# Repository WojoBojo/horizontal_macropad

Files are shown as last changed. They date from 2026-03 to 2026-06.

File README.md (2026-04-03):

# WojRaf's macropad
A wireless 16 key horizontal macropad, made for Hack Club Blueprint 2026

I always liked the idea of macropads, but I didn't like the "box" style (usualy a 4 x 4 grid of buttons). What I wanted was a horizontal (1 x 16 grid of buttons) version, that I could put on top of my keyboard (like a row of function keys).

So I came up with something like this:


The biggest challenge was the PCB - I started learning how to make one in KiCad, but I ended up using EasyEDA because in my opinion it is a bit more user-friendly.



The hardware consists of:

- ESP32 S3 Wroom 1
- 16 Kalih BOX switches
- Alps Alpine rotary encoder
- USB-C port for charging and programing
- 18650 2600mAh 3.7V battery

# How to use
1. Plug in the macropad via cable to your computer.

2. Open the macropad.ino file in Arduino IDE, select ESP32S3 Dev Module as the board and flash the firmware.

2. With the macropad still connected via cable, open the serial monitor, and chose 115200 as the baud rate.

# Commands
list - shows the current key mapping.

bind - changes the key's function (example: bind 5 F1 - changes key nr. 5 to F1 (Function 1 key)).

save - saves the changes to flash (keeps data after restart)

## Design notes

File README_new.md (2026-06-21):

# Horizontal Macropad 🎹



A wireless 16-key horizontal macropad, designed for [Hack Club Blueprint 2026](https://blueprint.hackclub.com).

I always liked macropads but never liked the boxy 4×4 grid. I wanted a horizontal row — like a function key row — that sits on top of your keyboard. So I built one.

---

## ✨ Features

| Feature | Details |
|---|---|
| **16 keys** | Kailh BOX switches via CD74HC4067 mux (saves GPIOs) |
| **Rotary encoder** | EC11E1834403 (ALPS) — volume / scroll by default |
| **Battery** | 18650 2600mAh with BQ24074 charger + TPS63031 buck-boost |
| **USB-C** | Charging only (data lines unpopulated) |
| **Wireless** | ESP32-S3 + on-board PCB antenna |
| **Persistent keymap** | Save key bindings to flash — survive reboot |
| **Configurable** | Remap any key over serial — no reflashing needed |

---

## 📁 Repository Structure

```
hardware/            ← PCB design files
├── PCB.pdf          ← PCB layout printable
├── PCB.png          ← PCB layout preview
├── Schematic.pdf    ← Circuit schematic printable
├── Schematic.png    ← Circuit schematic preview
└── EasyEDA/         ← Editable source files (EasyEDA Pro)
    ├── PCB.epro
    └── Schematic.epro

case/                ← 3D-printed enclosure
├── MacropadCase.step   ← STEP file (CAD)
└── MacropadCase_.f3z   ← Fusion 360 archive

firmware/            ← ESP32-S3 code
├── HackClub_Macropad.ino       ← Original firmware (minimal)
└── HackClub_Macropad_new.ino   ← Full rewrite (encoder, battery, keymap)

manufacturing/       ← Ready-to-order files
└── gerbers.zip      ← PCB Gerber + drill + flying probe

BOM.csv              ← Bill of Materials (LCSC part numbers)

README.md            ← This file (original)
README_new.md        ← This file (updated)
```

---

## 🚀 Quick Start

### 1. Order the PCB
Upload `manufacturing/gerbers.zip` + `BOM.csv` to [JLCPCB](https://jlcpcb.com) or your preferred fab.

| Item | Est. cost (5 pcs) |
|---|---|
| PCB 302×38mm (2-layer) | ~$20 |
| PCBA (top side assembly) | ~$40 |
| Components (LCSC) | ~$45 |
| **Total prototype** | **~$105** |

### 2. Print the case
`case/MacropadCase.step` — print on any FDM or resin printer.

### 3. Flash the firmware

**Recommended:** `firmware/HackClub_Macropad_new.ino`
- Open in **Arduino IDE 2.x**
- Board: `ESP32S3 Dev Module`
- Flash via **UART** (GPIO43=TX, GPIO44=RX) or solder 0Ω resistors on pads e40/e41 for native USB

> ⚠️ **Programming note:** USB-C on this board is charging-only. Data lines are unpopulated. Use a USB-UART adapter (e.g. CP2102) connected to GPIO43/44, or populate 0Ω resistors to enable native USB.

### 4. Configure key bindings

Open Serial Monitor at **115200 baud**:

```
list              → show current key map
bind 5 F1         → set key #5 to F1
bind 0 A          → set key #0 to letter A
save              → persist to flash (survives reboot)
load              → reload from flash
default           → restore factory defaults
battery           → show battery voltage
encoder           → show encoder position
```

### 5. Mount on keyboard
The horizontal form sits perfectly above your function keys. Use double-sided tape or screw holes (add your own — PCB doesn't include M3 holes in this rev).

---

## 🔌 Pin Map

| Signal | GPIO | Function |
|---|---|---|
| MUX_OUT | 1 | CD74HC4067 common (pull-up) |
| S0–S3 | 4–7 | Mux address lines |
| ENC_A | 18 | Rotary encoder phase A |
| ENC_B | 19 | Rotary encoder phase B (no conflict — USB data NC) |
| ENC_SW | — | **Not routed** on this PCB (pads D/E empty) |
| BAT_ADC | 39 | Battery voltage divider (ADC1) |

---

## 🛠 PCB Revision Notes

This is **v1.0** of the design. Things to fix in the next spin:

- [ ] **Add ground pour** — no copper fill on either layer → EMI risk for ESP32 @240MHz
- [ ] **Add M3 mounting holes** — 300mm board needs mechanical support
- [ ] **External pull-up on MUX_OUT** — internal INPUT_PULLUP (~45k) is marginal on long traces
- [ ] **Wire encoder push button** — pads D/E of EC11E1834403 are unconnected
- [ ] **TVS diode on VBUS** — ESD protection for USB-C
- [ ] **Thicker power traces** — VBAT and 3.3V should be ≥0.5mm wide

---

## 🏆 Made For Hack Club Blueprint 2026

Built from scratch — KiCad → EasyEDA → breadboard → PCB → case → firmware.

Thanks to [Hack Club](https://hackclub.com) for the opportunity and funding!

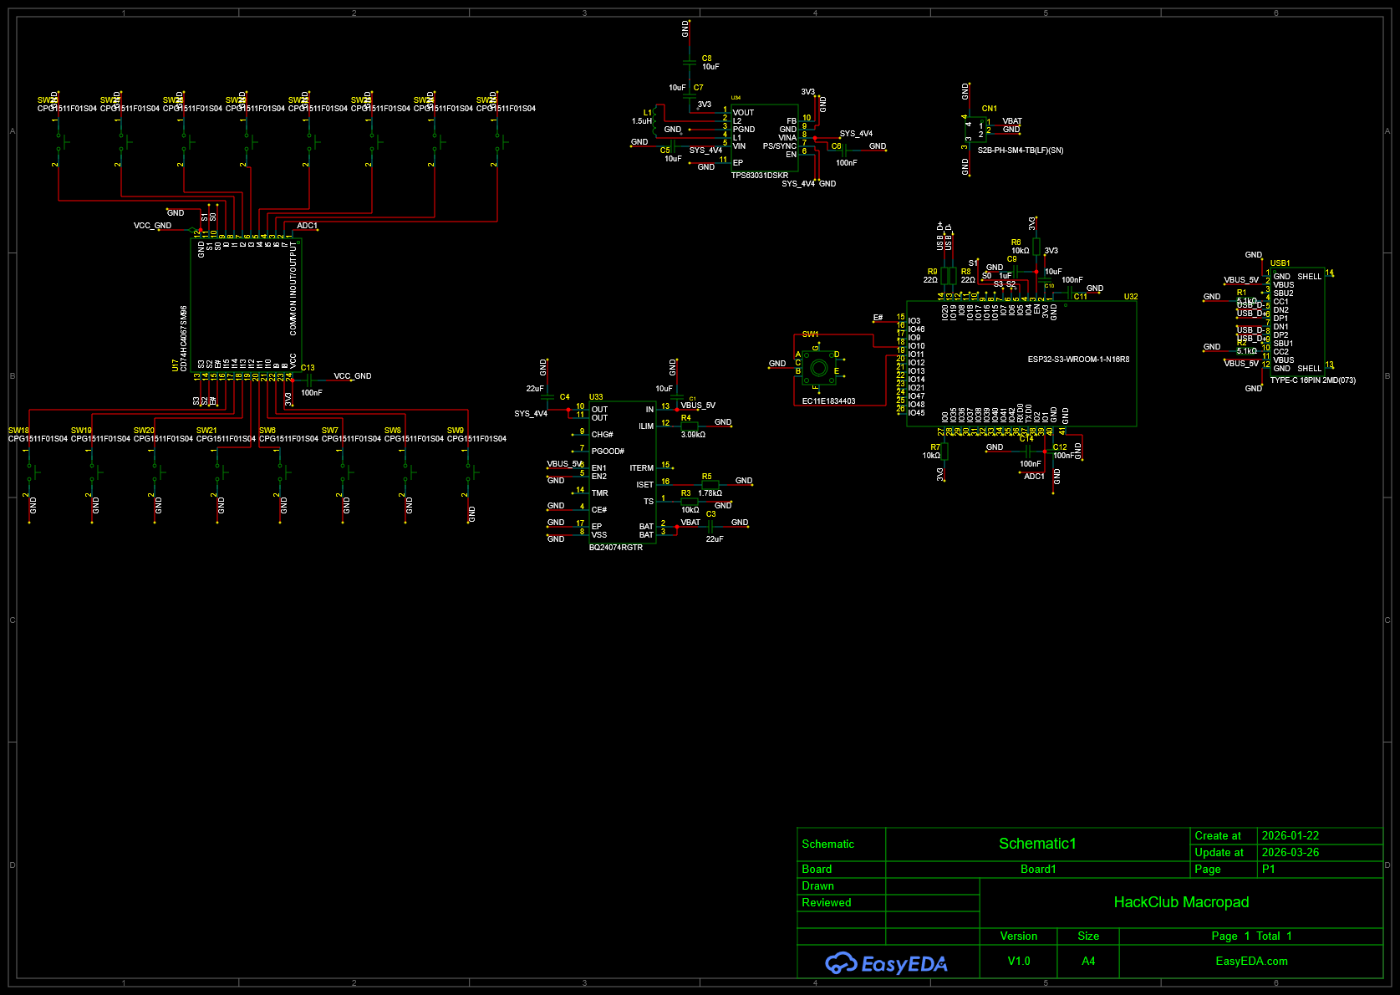
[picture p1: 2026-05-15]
hardware/Schematic.png

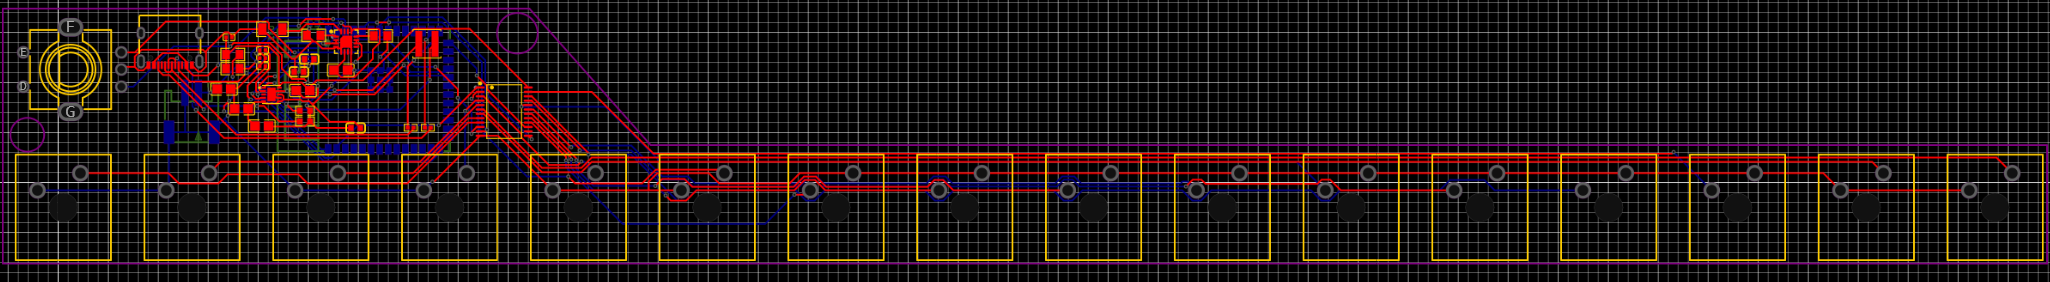
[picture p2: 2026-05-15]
hardware/PCB.png

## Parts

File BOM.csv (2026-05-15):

No. | Quantity | Comment | Designator | Footprint | Value | Manufacturer Part | Manufacturer | Supplier Part | Links
1 | 16 | CPG1511F01S04 | SW6,SW7,SW8,SW9,SW18,SW19,SW20,SW21,SW22,SW23,SW24,SW25,SW26,SW27,SW28,SW29 | KEY-TH_CPG1511F01S0X |  | CPG1511F01S04 | Kailh(凯华) | C400226 | https://www.kailh.net/products/kailh-box-switch-set?variant=43810892284146
2 | 4 | 100nF | C11,C12,C13,C14 | C0402 | 100nF | CL05B104KB54PNC | SAMSUNG(三星) | C307331 | https://www.lcsc.com/product-detail/C307331.html?s_z=n_C307331
3 | 3 | 10uF | C5,C7,C8 | C0603 | 10uF | CL10A106KP8NNNC | SAMSUNG(三星) | C19702 | https://www.lcsc.com/product-detail/C19702.html?s_z=n_C19702
4 | 2 | 5.1kΩ | R1,R2 | R0603 | 5.1kΩ | 0603WAF5101T5E | UNI-ROYAL(厚声) | C23186 | https://www.lcsc.com/product-detail/C23186.html?s_z=n_C23186
5 | 2 | 10uF | C1,C10 | C0805 | 10uF | CC0805KKX5R7BB106 | YAGEO(国巨) | C89827 | https://www.lcsc.com/product-detail/C89827.html?s_z=n_C89827
6 | 2 | 22uF | C3,C4 | C0805 | 22uF | CL21A226MPQNNNE | SAMSUNG(三星) | C29277 | https://www.lcsc.com/product-detail/C29277.html?s_z=n_C29277
7 | 2 | 10kΩ | R6,R7 | R0805 | 10kΩ | RC0805FR-0710KL | YAGEO(国巨) | C84376 | https://www.lcsc.com/product-detail/C84376.html?s_z=n_C84376
8 | 2 | 22Ω | R8,R9 | R0402 | 22Ω | RC0402FR-0722RL | YAGEO(国巨) | C114765 | https://www.lcsc.com/product-detail/C114765.html?s_z=n_C114765
9 | 1 | CD74HC4067SM96 | U17 | SSOP-24_L8.1-W5.3-P0.65-LS7.8-BL |  | CD74HC4067SM96 | TI(德州仪器) | C98457 | https://www.lcsc.com/product-detail/C98457.html?s_z=n_C98457
10 | 1 | ESP32-S3-WROOM-1-N16R8 | U32 | WIRELM-SMD_ESP32-S3-WROOM-1 |  | ESP32-S3-WROOM-1-N16R8 | ESPRESSIF(乐鑫) | C2913202 | https://www.lcsc.com/product-detail/C2913202.html?s_z=n_C2913202
11 | 1 | TYPE-C 16PIN 2MD(073) | USB1 | USB-C-SMD_TYPE-C-6PIN-2MD-073 |  | TYPE-C 16PIN 2MD(073) | SHOU HAN(首韩) | C2765186 | https://www.lcsc.com/product-detail/C2765186.html?s_z=n_C2765186
12 | 1 | S2B-PH-SM4-TB(LF)(SN) | CN1 | CONN-SMD_P2.00_S2B-PH-SM4-TB-LF-SN |  | S2B-PH-SM4-TB(LF)(SN) | JST | C295747 | https://www.lcsc.com/product-detail/C295747.html?s_z=n_C295747
13 | 1 | BQ24074RGTR | U33 | QFN-16_L3.0-W3.0-P0.50-TL-EP1.7 |  | BQ24074RGTR | TI(德州仪器) | C54313 | https://www.lcsc.com/product-detail/C54313.html?s_z=n_C54313
14 | 1 | TPS63031DSKR | U34 | SON-10_L2.5-W2.5-P0.50-TL-EP |  | TPS63031DSKR | TI(德州仪器) | C15516 | https://www.lcsc.com/product-detail/C15516.html?s_z=n_C15516
15 | 1 | 10kΩ | R3 | R0805 | 10kΩ | 0805W8F1002T5E | UNI-ROYAL(厚声) | C17414 | https://www.lcsc.com/product-detail/C17414.html?s_z=n_C17414
16 | 1 | 3.09kΩ | R4 | R0805 | 3.09kΩ | RT0805BRD073K09L | YAGEO(国巨) | C865456 | https://www.lcsc.com/product-detail/C865456.html?s_z=n_C865456
17 | 1 | 1.78kΩ | R5 | R1206 | 1.78kΩ | RT1206BRD071K78L | YAGEO(国巨) | C706404 | https://www.lcsc.com/product-detail/C706404.html?s_z=n_C706404
18 | 1 | 1.5uH | L1 | IND-SMD_L4.0-W4.0-A | 1.5uH | XFL4020-152MEC | Coilcraft(线艺) | C3033018 | https://www.lcsc.com/product-detail/C3033018.html?s_z=n_C3033018
19 | 1 | 100nF | C6 | C0805 | 100nF | CC0805KRX7R9BB104 | YAGEO(国巨) | C49678 | https://www.lcsc.com/product-detail/C49678.html?s_z=n_C49678
20 | 1 | 1uF | C9 | C0402 | 1uF | 0402X105K160NT | FH(风华) | C167339 | https://www.lcsc.com/product-detail/C167339.html?s_z=n_C167339
21 | 1 | EC11E1834403 | SW1 | SW-TH_EC11E1820402 |  | EC11E1834403 | ALPSALPINE(阿尔卑斯阿尔派) | C361165 | https://www.lcsc.com/product-detail/C361165.html?s_z=n_C361165
22 | 1 | 18650 battery |  |  |  |  |  |  | https://pl.aliexpress.com/item/1005009524416323.html

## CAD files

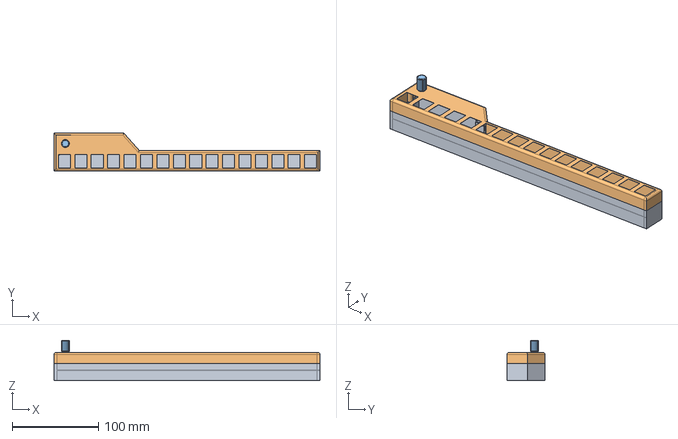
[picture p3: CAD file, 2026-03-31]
case/MacropadCase.step
308.8 x 44.1 x 46.8 mm

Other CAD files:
case/MacropadCase_.f3z

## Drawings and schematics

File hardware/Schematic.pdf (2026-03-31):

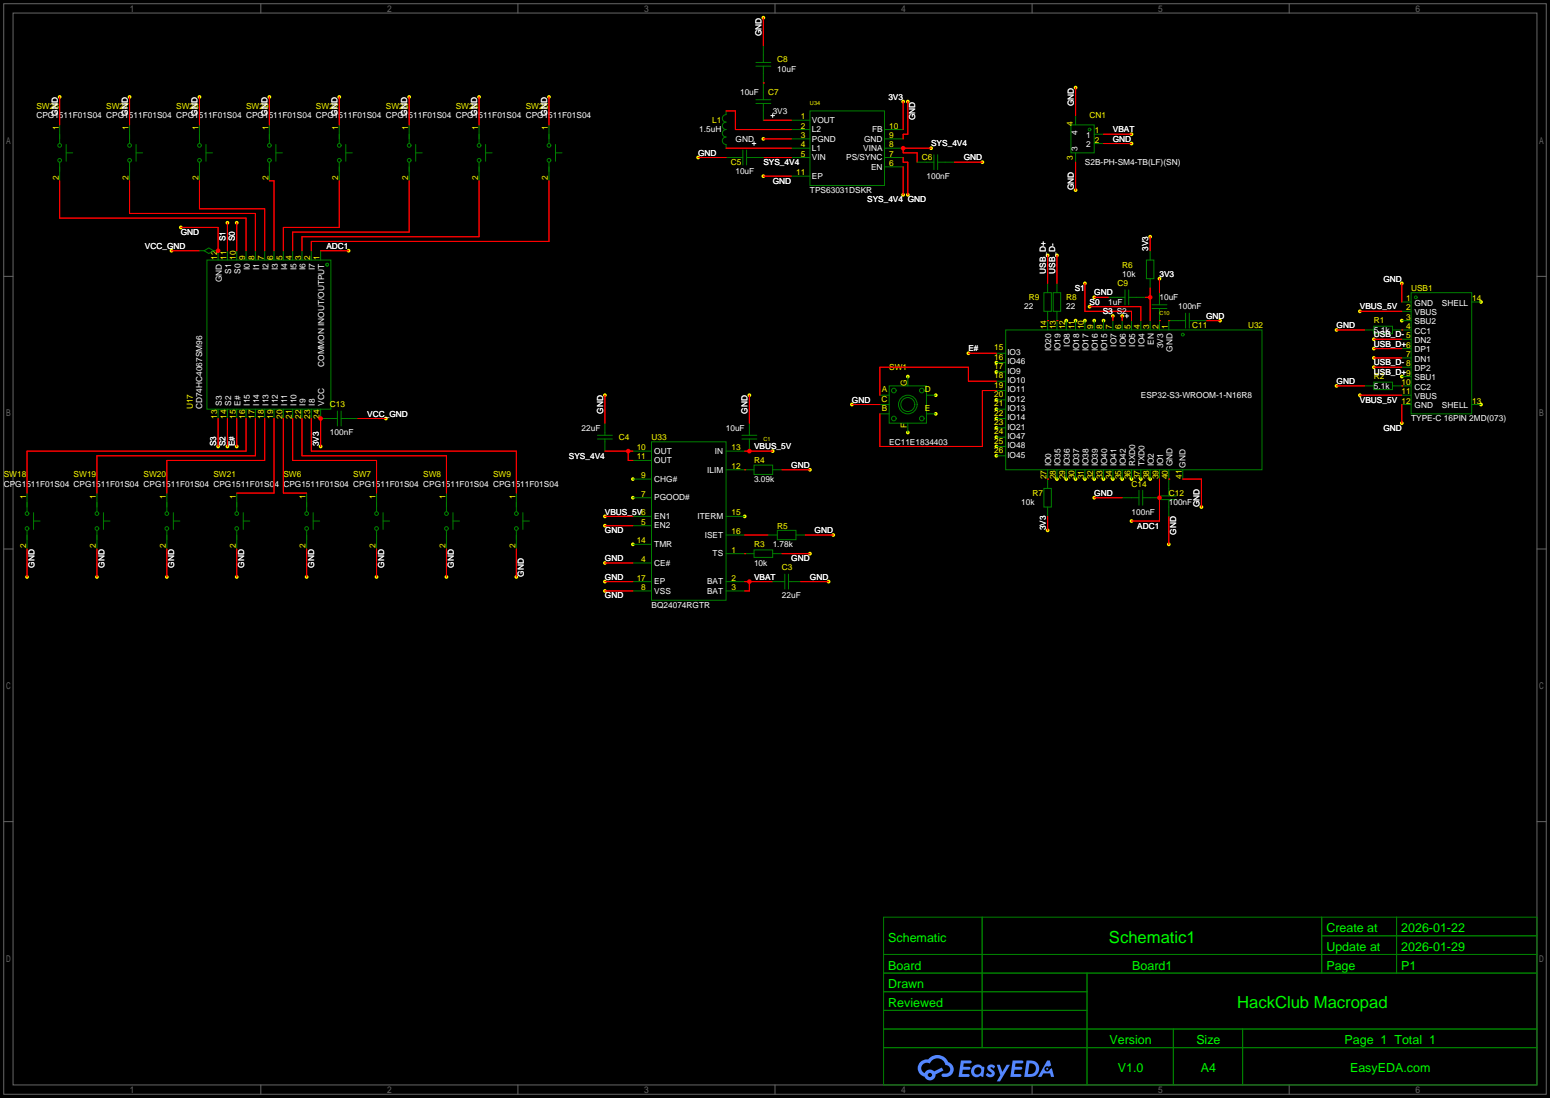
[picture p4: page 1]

Schematic | Schematic1 | Create at | 2026-01-22

Update at | 2026-01-29

Board | Board1 | Page | P1
Drawn | | HackClub Macropad
Reviewed

Version | Size | Page 1 Total 1
V1.0 | A4 | EasyEDA.com

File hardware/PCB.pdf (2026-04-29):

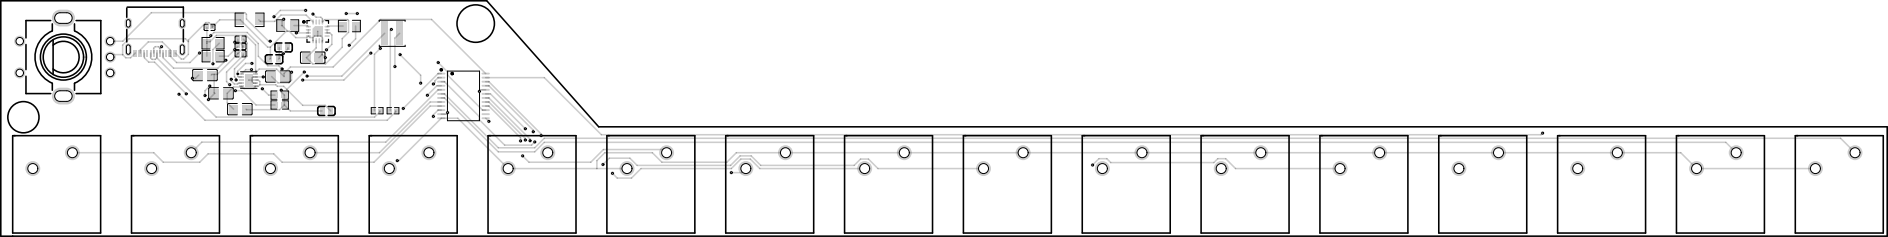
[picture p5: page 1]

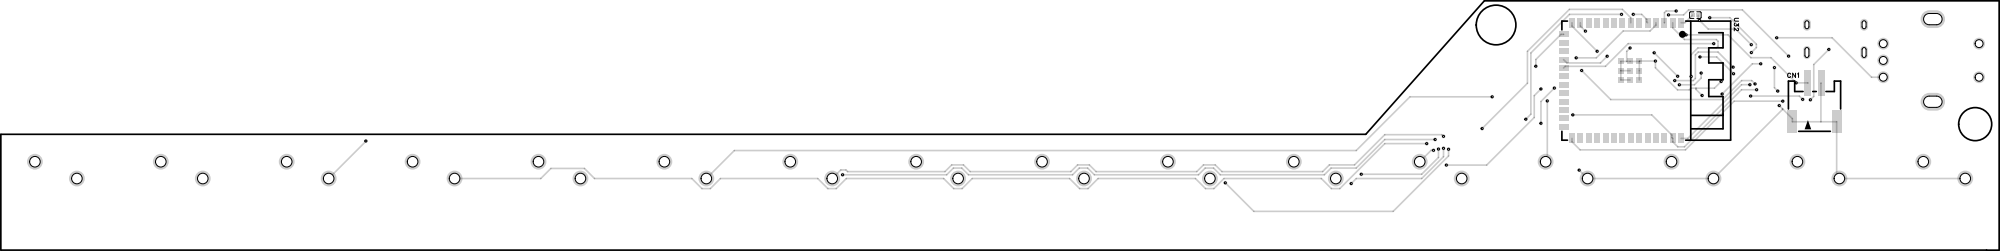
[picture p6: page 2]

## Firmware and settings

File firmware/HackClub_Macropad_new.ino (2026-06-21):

/*
 * Horizontal Macropad - Complete Firmware
 * ESP32-S3, 16x Kailh BOX switches via CD74HC4067 mux
 * + EC11E1834403 rotary encoder (GPIO18=A, GPIO19=B, switch NC)
 * + Battery monitoring (ADC1 = GPIO4)
 *
 * USB HID Keyboard + persistent keymap in flash.
 *
 * PIN MAP:
 *   S0-S3   = GPIO4-7    → Mux address lines
 *   MUX_OUT = GPIO1      → Mux COM (INPUT_PULLUP)
 *   ENC_A   = GPIO18     → Encoder phase A
 *   ENC_B   = GPIO19     → Encoder phase B
 *   BAT_ADC = GPIO39     → ADC monitoring (divider to VBAT)
 *
 * NOTE: Encoder switch (push button) is NOT wired on this PCB revision.
 *       Code is included but #ifdef'd out.
 * NOTE: USB data lines are charging-only. Program via UART0 (GPIO43 TX, GPIO44 RX)
 *       or solder 0Ω on e40/e41 for native USB.
 */

#include <Arduino.h>
#include "USBHIDKeyboard.h"
#include <Preferences.h>

// ============================================================
// PIN DEFINITIONS
// ============================================================

// Mux
const uint8_t S0 = 4;
const uint8_t S1 = 5;
const uint8_t S2 = 6;
const uint8_t S3 = 7;
const uint8_t MUX_OUT = 1;

// Rotary encoder
const uint8_t ENC_A = 18;
const uint8_t ENC_B = 19;
// Encoder push button: DNP on this PCB (pads D/E not routed)
// #define ENC_SW  21   // uncomment + wire if you add it later

// Battery ADC
const uint8_t BAT_ADC = 39;  // GPIO39 = ADC1_CH4 (from schematic: Pad 39 -> ADC1)

// ============================================================
// KEY MAP — stored in RTC memory for fast access, synced to flash
// ============================================================

// Default key assignments (HID usage codes)
// 16 physical keys, in order SW6-SW9 (ch0-3), SW18-SW29 (ch4-15)
// We store HID usage IDs for generic desktop keyboard page.
static const uint8_t DEFAULT_KEYS[16] = {
  HID_KEY_F1,  HID_KEY_F2,  HID_KEY_F3,  HID_KEY_F4,       // SW6-9
  HID_KEY_F5,  HID_KEY_F6,  HID_KEY_F7,  HID_KEY_F8,       // SW18-21
  HID_KEY_F9,  HID_KEY_F10, HID_KEY_F11, HID_KEY_F12,      // SW22-25
  HID_KEY_F13, HID_KEY_F14, HID_KEY_F15, HID_KEY_F16,      // SW26-29
};

// For the serial "bind" command we accept these short names:
struct KeyName {
  const char* name;
  uint8_t hid;
};
static const KeyName KEY_NAMES[] = {
  {"F1",  HID_KEY_F1},   {"F2",  HID_KEY_F2},   {"F3",  HID_KEY_F3},
  {"F4",  HID_KEY_F4},   {"F5",  HID_KEY_F5},   {"F6",  HID_KEY_F6},
  {"F7",  HID_KEY_F7},   {"F8",  HID_KEY_F8},   {"F9",  HID_KEY_F9},
  {"F10", HID_KEY_F10},  {"F11", HID_KEY_F11},  {"F12", HID_KEY_F12},
  {"F13", HID_KEY_F13},  {"F14", HID_KEY_F14},  {"F15", HID_KEY_F15},
  {"F16", HID_KEY_F16},  {"F17", HID_KEY_F17},  {"F18", HID_KEY_F18},
  {"F19", HID_KEY_F19},  {"F20", HID_KEY_F20},  {"F21", HID_KEY_F21},
  {"F22", HID_KEY_F22},  {"F23", HID_KEY_F23},  {"F24", HID_KEY_F24},
  {"A",   HID_KEY_A},    {"B",   HID_KEY_B},    {"C",   HID_KEY_C},
  {"D",   HID_KEY_D},    {"E",   HID_KEY_E},    {"F",   HID_KEY_F},
  {"G",   HID_KEY_G},    {"H",   HID_KEY_H},    {"I",   HID_KEY_I},
  {"J",   HID_KEY_J},    {"K",   HID_KEY_K},    {"L",   HID_KEY_L},
  {"M",   HID_KEY_M},    {"N",   HID_KEY_N},    {"O",   HID_KEY_O},
  {"P",   HID_KEY_P},    {"Q",   HID_KEY_Q},    {"R",   HID_KEY_R},
  {"S",   HID_KEY_S},    {"T",   HID_KEY_T},    {"U",   HID_KEY_U},
  {"V",   HID_KEY_V},    {"W",   HID_KEY_W},    {"X",   HID_KEY_X},
  {"Y",   HID_KEY_Y},    {"Z",   HID_KEY_Z},
  {"0",   HID_KEY_0},    {"1",   HID_KEY_1},    {"2",   HID_KEY_2},
  {"3",   HID_KEY_3},    {"4",   HID_KEY_4},    {"5",   HID_KEY_5},
  {"6",   HID_KEY_6},    {"7",   HID_KEY_7},    {"8",   HID_KEY_8},
  {"9",   HID_KEY_9},
  {"ENTER",  HID_KEY_ENTER},  {"ESC",   HID_KEY_ESCAPE},
  {"TAB",    HID_KEY_TAB},    {"SPACE", HID_KEY_SPACE},
  {"BKSP",   HID_KEY_BACKSPACE}, {"DEL", HID_KEY_DELETE},
  {"INS",    HID_KEY_INSERT}, {"HOME",  HID_KEY_HOME},
  {"END",    HID_KEY_END},    {"PGUP",  HID_KEY_PAGE_UP},
  {"PGDN",   HID_KEY_PAGE_DOWN},
  {"LCTRL",  HID_KEY_CONTROL_LEFT},  {"RCTRL",  HID_KEY_CONTROL_RIGHT},
  {"LSHIFT", HID_KEY_SHIFT_LEFT},    {"RSHIFT", HID_KEY_SHIFT_RIGHT},
  {"LALT",   HID_KEY_ALT_LEFT},      {"RALT",   HID_KEY_ALT_RIGHT},
  {"LGUI",   HID_KEY_GUI_LEFT},      {"RGUI",   HID_KEY_GUI_RIGHT},
  {nullptr, 0}
};

RTC_DATA_ATTR uint8_t keyMap[16];
RTC_DATA_ATTR bool    keyMapLoaded = false;
Preferences prefs;

// ============================================================
// STATE
// ============================================================

USBHIDKeyboard Keyboard;

// Button debounce
bool   wasPressed[16] = {false};
uint32_t lastDebounce[16] = {0};
const uint32_t DEBOUNCE_US = 5000;  // 5ms

// Encoder
volatile int16_t encoderPos = 0;
int16_t          lastEncPos = 0;
uint32_t         lastEncTime = 0;

// Battery
uint32_t lastBatteryRead = 0;
const uint32_t BATTERY_INTERVAL_MS = 30000;  // every 30s
float batteryVoltage = 0.0f;

// ============================================================
// MUX HELPERS
// ============================================================

void setMux(int ch) {
  digitalWrite(S0, ch & 1);
  digitalWrite(S1, (ch >> 1) & 1);
  digitalWrite(S2, (ch >> 2) & 1);
  digitalWrite(S3, (ch >> 3) & 1);
  delayMicroseconds(10);  // plenty for CD74HC4067 settle (~200ns)
}

// ============================================================
// KEY LOOKUP
// ============================================================

uint8_t nameToHid(const char* name) {
  for (int i = 0; KEY_NAMES[i].name != nullptr; i++) {
    if (strcasecmp(name, KEY_NAMES[i].name) == 0)
      return KEY_NAMES[i].hid;
  }
  return 0;
}

const char* hidToName(uint8_t hid) {
  for (int i = 0; KEY_NAMES[i].name != nullptr; i++) {
    if (KEY_NAMES[i].hid == hid)
      return KEY_NAMES[i].name;
  }
  return "?";
}

// ============================================================
// ENCODER ISR
// ============================================================

void IRAM_ATTR encoderISR() {
  static uint8_t prev = 0;
  uint8_t ab = (digitalRead(ENC_A) << 1) | digitalRead(ENC_B);
  // Standard lookup table for KY-040 / EC11
  static const int8_t table[16] = {
    0,  1, -1,  0,   // 00→01=CW, 00→10=CCW
   -1,  0,  0,  1,   // 01→00=CCW, 01→11=CW
    1,  0,  0, -1,   // 10→00=CW, 10→11=CCW
    0, -1,  1,  0    // 11→01=CCW, 11→10=CW
  };
  int8_t step = table[(prev << 2) | ab];
  if (step) {
    encoderPos += step;
    prev = ab;
  }
}

// ============================================================
// SERIAL COMMANDS
// ============================================================

void printHelp() {
  Serial.println(F(
    "\nCommands:"
    "\n  list              - show current key mapping"
    "\n  bind <n> <key>    - set key n (0-15) to key name (F1, A, ENTER, etc.)"
    "\n  save              - save mapping to flash"
    "\n  load              - reload mapping from flash"
    "\n  default           - restore default mapping"
    "\n  battery           - show battery voltage"
    "\n  encoder           - show encoder position"
    "\n  resetenc          - reset encoder position to 0"
    "\n  help              - this message"
  ));
}

void cmdList() {
  Serial.println(F("\nCurrent keymap:"));
  for (int i = 0; i < 16; i++) {
    char buf[32];
    snprintf(buf, sizeof(buf), "  %2d: %s (0x%02X)", i, hidToName(keyMap[i]), keyMap[i]);
    Serial.println(buf);
  }
  Serial.print(F("\nBattery: "));
  Serial.print(batteryVoltage, 2);
  Serial.println(F(" V"));
  Serial.print(F("Encoder: "));
  Serial.println(encoderPos);
}

void cmdBind(int n, const char* keyName) {
  if (n < 0 || n > 15) {
    Serial.println(F("Error: key index must be 0-15"));
    return;
  }
  uint8_t hid = nameToHid(keyName);
  if (hid == 0) {
    Serial.print(F("Error: unknown key '"));
    Serial.print(keyName);
    Serial.println(F("'. Type 'help' for names."));
    return;
  }
  keyMap[n] = hid;
  Serial.print(F("OK: key "));
  Serial.print(n);
  Serial.print(F(" -> "));
  Serial.println(hidToName(hid));
}

void cmdSave() {
  prefs.begin("macropad", false);
  prefs.putBytes("keymap", keyMap, 16);
  prefs.end();
  Serial.println(F("Saved to flash."));
}

void cmdLoad() {
  prefs.begin("macropad", true);
  size_t sz = prefs.getBytes("keymap", keyMap, 16);
  prefs.end();
  if (sz == 16) {
    Serial.println(F("Loaded from flash."));
  } else {
    Serial.println(F("No saved map, using defaults."));
    memcpy(keyMap, DEFAULT_KEYS, 16);
  }
}

void cmdDefault() {
  memcpy(keyMap, DEFAULT_KEYS, 16);
  Serial.println(F("Default keymap restored."));
}

void processSerial() {
  if (!Serial.available()) return;

  char line[64];
  size_t len = Serial.readBytesUntil('\n', line, sizeof(line) - 1);
  line[len] = '\0';

  // Trim trailing whitespace
  while (len > 0 && (line[len-1] == '\r' || line[len-1] == ' ' || line[len-1] == '\t'))
    line[--len] = '\0';

  if (len == 0) return;

  char* cmd = strtok(line, " ");

  if (strcasecmp(cmd, "help") == 0) {
    printHelp();
  } else if (strcasecmp(cmd, "list") == 0) {
    cmdList();
  } else if (strcasecmp(cmd, "bind") == 0) {
    char* n_str = strtok(nullptr, " ");
    char* keyName = strtok(nullptr, " ");
    if (n_str && keyName) {
      cmdBind(atoi(n_str), keyName);
    } else {
      Serial.println(F("Usage: bind <0-15> <KEYNAME>"));
    }
  } else if (strcasecmp(cmd, "save") == 0) {
    cmdSave();
  } else if (strcasecmp(cmd, "load") == 0) {
    cmdLoad();
  } else if (strcasecmp(cmd, "default") == 0) {
    cmdDefault();
  } else if (strcasecmp(cmd, "battery") == 0) {
    readBattery();
    Serial.print(F("Battery: "));
    Serial.print(batteryVoltage, 2);
    Serial.println(F(" V"));
  } else if (strcasecmp(cmd, "encoder") == 0) {
    Serial.print(F("Encoder position: "));
    Serial.println(encoderPos);
  } else if (strcasecmp(cmd, "resetenc") == 0) {
    encoderPos = 0;
    Serial.println(F("Encoder reset to 0."));
  } else {
    Serial.print(F("Unknown: '"));
    Serial.print(cmd);
    Serial.println(F("'. Type 'help'."));
  }
}

// ============================================================
// BATTERY
// ============================================================

void readBattery() {
  // TODO: Calibrate divider ratio from actual schematic.
  // Default: assume 2:1 divider (max reading = 2*3.3V = 6.6V, OK for 4.2V Li-ion)
  int raw = analogRead(BAT_ADC);
  float mv = analogReadMilliVolts(BAT_ADC);  // ESP32-S3 has built-in millivolt read
  // If using voltage divider R3+R4: Vbatt = mV * (R3+R4)/R4
  // For 100k+100k divider: factor = 2.0
  // For now assume 2:1
  batteryVoltage = mv * 2.0f / 1000.0f;
}

// ============================================================
// SETUP
// ============================================================

void setup() {
  Serial.begin(115200);
  delay(500);
  Serial.println(F("\n=== Horizontal Macropad ==="));

  // Mux address pins
  pinMode(S0, OUTPUT);
  pinMode(S1, OUTPUT);
  pinMode(S2, OUTPUT);
  pinMode(S3, OUTPUT);
  pinMode(MUX_OUT, INPUT_PULLUP);

  // Encoder
  pinMode(ENC_A, INPUT_PULLUP);
  pinMode(ENC_B, INPUT_PULLUP);
  attachInterrupt(digitalPinToInterrupt(ENC_A), encoderISR, CHANGE);
  attachInterrupt(digitalPinToInterrupt(ENC_B), encoderISR, CHANGE);
  /*
  // If encoder switch is wired (not on this PCB rev):
  pinMode(ENC_SW, INPUT_PULLUP);
  */

  // Battery ADC
  analogReadResolution(12);  // 0-4095
  pinMode(BAT_ADC, INPUT);

  // Keymap
  if (!keyMapLoaded) {
    prefs.begin("macropad", true);
    size_t sz = prefs.getBytes("keymap", keyMap, 16);
    prefs.end();
    if (sz != 16) {
      memcpy(keyMap, DEFAULT_KEYS, 16);
    }
    keyMapLoaded = true;
  }

  Keyboard.begin();
  Serial.println(F("Keyboard ready."));

  // Initial battery read
  readBattery();
  Serial.print(F("Battery: "));
  Serial.print(batteryVoltage, 2);
  Serial.println(F(" V"));

  printHelp();
}

// ============================================================
// LOOP
// ============================================================

void loop() {
  uint32_t now = micros();

  // --- 1. Scan key matrix ---
  for (int i = 0; i < 16; i++) {
    setMux(i);

    bool pressed = (digitalRead(MUX_OUT) == LOW);

    if (pressed && !wasPressed[i]) {
      if (now - lastDebounce[i] > DEBOUNCE_US) {
        lastDebounce[i] = now;
        wasPressed[i] = true;
        Keyboard.press(keyMap[i]);
      }
    } else if (!pressed && wasPressed[i]) {
      if (now - lastDebounce[i] > DEBOUNCE_US) {
        lastDebounce[i] = now;
        wasPressed[i] = false;
        Keyboard.release(keyMap[i]);
      }
    }
  }

  // --- 2. Encoder ---
  noInterrupts();
  int16_t pos = encoderPos;
  interrupts();

  if (pos != lastEncPos) {
    int16_t delta = pos - lastEncPos;
    lastEncPos = pos;
    // Send scroll/arrow keys based on direction
    while (delta > 0) {
      Keyboard.press(HID_KEY_ARROW_UP);
      delay(2);
      Keyboard.release(HID_KEY_ARROW_UP);
      delta--;
    }
    while (delta < 0) {
      Keyboard.press(HID_KEY_ARROW_DOWN);
      delay(2);
      Keyboard.release(HID_KEY_ARROW_DOWN);
      delta++;
    }
    lastEncTime = now;
  }

  /*
  // Encoder switch (uncomment when wired)
  static bool encSwLast = HIGH;
  bool encSwNow = digitalRead(ENC_SW);
  if (encSwLast == HIGH && encSwNow == LOW) {
    // Pressed: send ENTER or mute
    Keyboard.press(HID_KEY_ENTER);
    delay(2);
    Keyboard.release(HID_KEY_ENTER);
    delay(50);  // simple debounce
  }
  encSwLast = encSwNow;
  */

  // --- 3. Battery (periodic) ---
  if (millis() - lastBatteryRead > BATTERY_INTERVAL_MS) {
    readBattery();
    lastBatteryRead = millis();
  }

  // --- 4. Serial commands ---
  processSerial();

  delay(4);  // ~250 Hz loop
}

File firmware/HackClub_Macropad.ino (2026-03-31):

#include <Arduino.h>
#include "USBHIDKeyboard.h"

USBHIDKeyboard Keyboard;

//Mux address pins
const uint8_t S0 = 4;
const uint8_t S1 = 5;
const uint8_t S2 = 6;
const uint8_t S3 = 7;

//Mux common output pin (the pin the COM of the mux is connected to)
const uint8_t MUX_OUT = 1;     // <-- change if you used a different pin

// default keymap
char keyMap[16] = {'1','2','3','4','Q','W','E','R','A','S','D','F','Z','X','C','V'};

bool wasPressed[16] = {false};

void setup() {
  Keyboard.begin();
  Serial.begin(115200);

  //Set mux address pins as outputs
  pinMode(S0, OUTPUT);
  pinMode(S1, OUTPUT);
  pinMode(S2, OUTPUT);
  pinMode(S3, OUTPUT);

  pinMode(MUX_OUT, INPUT_PULLUP);

  Serial.println("macropad ready");
  Serial.println("type help if you want");
}

void setMux(int ch) {
  digitalWrite(S0, ch & 1);
  digitalWrite(S1, (ch >> 1) & 1);
  digitalWrite(S2, (ch >> 2) & 1);
  digitalWrite(S3, (ch >> 3) & 1);
  delayMicroseconds(50);
}

void loop() {
  for (int i = 0; i < 16; i++) {
    setMux(i);
    
    bool pressed = (digitalRead(MUX_OUT) == LOW);

    if (pressed && !wasPressed[i]) {
      Keyboard.press(keyMap[i]);
      wasPressed[i] = true;
    } 
    else if (!pressed && wasPressed[i]) {
      Keyboard.release(keyMap[i]);
      wasPressed[i] = false;
    }
  }

  delay(5);
}

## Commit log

2026-03-31 Update HackClub Macropad BOM - BOM_Board1_Schematic1_2026-03-2.csv
    [HackClub Macropad BOM - BOM_Board1_Schematic1_2026-03-2.csv]
2026-05-15 Rename HackClub Macropad BOM - BOM_Board1_Schematic1_2026-03-2.csv to HackClub Macropad BOM.csv
    [HackClub Macropad BOM.csv]
2026-05-15 Update HackClub Macropad BOM.csv
    [HackClub Macropad BOM.csv]
2026-06-21 Add new firmware with encoder, battery monitoring, persistent keymap
    Adds full firmware rewrite:
    - 16-key matrix scanning via CD74HC4067 mux
    - EC11 rotary encoder on GPIO18/19 (A/B phase)
    - Battery voltage monitoring on GPIO39 (ADC1)
    - Persistent keymap in flash (via Preferences)
    - Serial commands: list, bind, save, load, default
    - 60+ HID key names for binding
    - Debounce and encoder ISR with lookup table
    Leaves original HackClub_Macropad.ino untouched as backup.
    Renamed to HackClub_Macropad_new.ino for comparison.
    [HackClub_Macropad_new.ino]
2026-06-21 Organize repo structure + add README_new
    - Rename HackClub Macropad BOM.csv → BOM.csv (no spaces)
    - Move PCB files to hardware/ with readable extensions (.pdf, .png)
    - Move EasyEDA sources to hardware/EasyEDA/
    - Move gerbers zip to manufacturing/gerbers.zip
    - Add README_new.md with full documentation
    [BOM.csv]
